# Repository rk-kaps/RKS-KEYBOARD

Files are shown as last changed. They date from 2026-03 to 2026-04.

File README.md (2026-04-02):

# RKS-Keyboard

A mechanical keyboard build on YD-RP2040 with an OLED display and backlights

Build for **MX** switches

A sligthly modified 96% keyboard layout with 4 extra keys for managing onboard firmware (103 keys total)

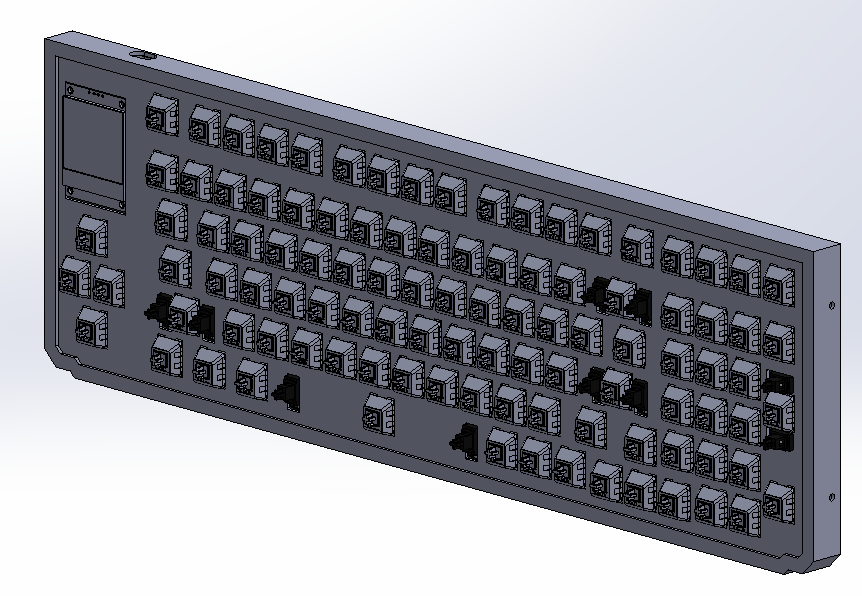
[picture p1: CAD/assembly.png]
Keyboard CAD assembly


Keyboard layout

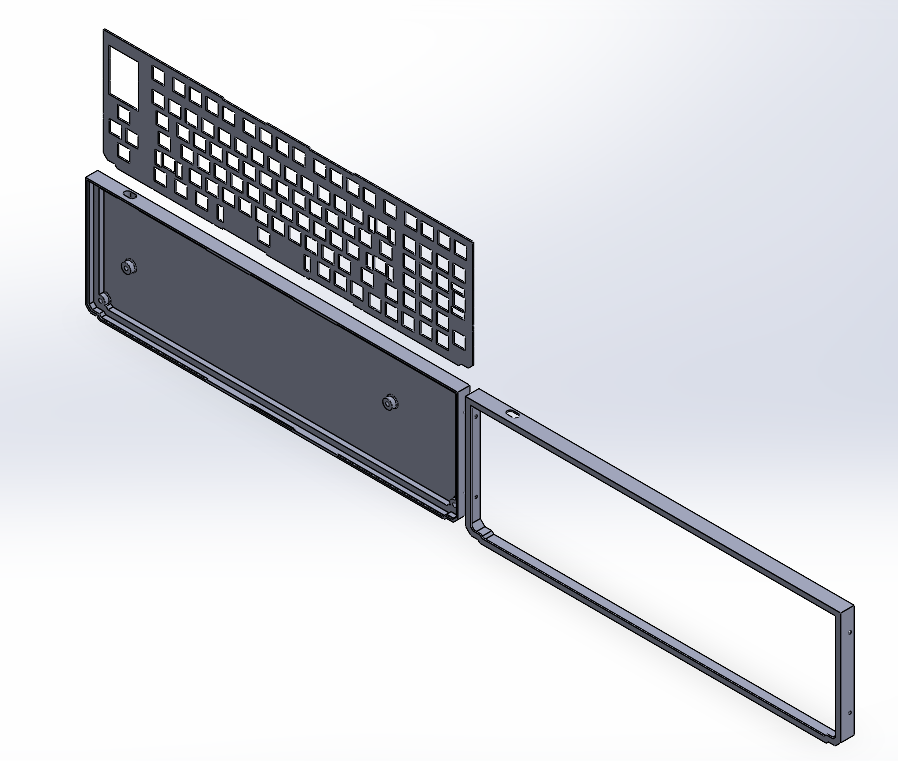
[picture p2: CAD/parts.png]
Keyboard parts


## Why is this one special

It's a keyboard with a customisable OLED that helps to manage, and control parts of the firmware like changing backlighting color, showing typing speed and much more

The firmware is also open-source so anyone can customise and add features to their keyboard

## PCB

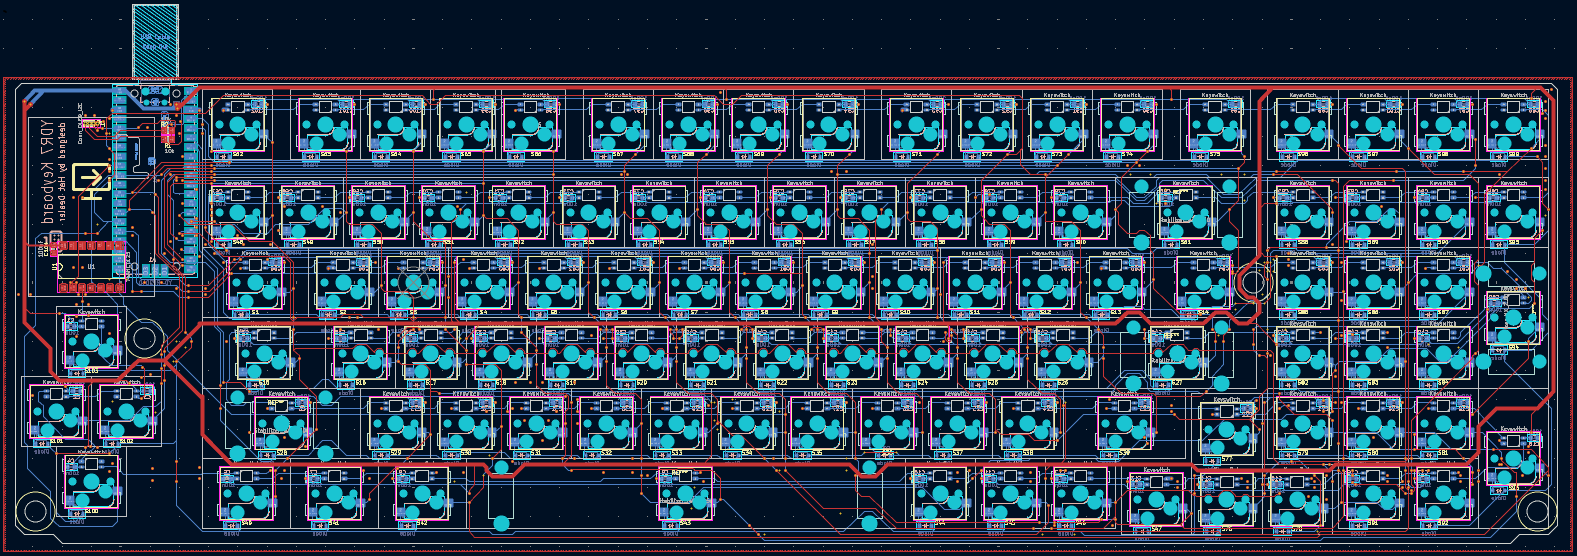
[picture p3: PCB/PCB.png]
PCB


The keyboard uses a custom PCB with the YD-RP2040 attached to it providing a USB-C connection along with power to the board

The YD-RP2040 is the devboard with a chip running this project. You may be able to use a standard Raspberry PI pico but that was not tested

## Case

The keyboard is comprised out of 3 parts. The panel which holds the switches, a back panel and a front panel

Due to their size its impossible to print an entire piece at once, thats why there are sliced versions in the `CAD/Sliced` folder. You can print them separately and then weld them with a soldering iron together. You should weld the front and the back piece but not the panels as they are held together by the frame anyway

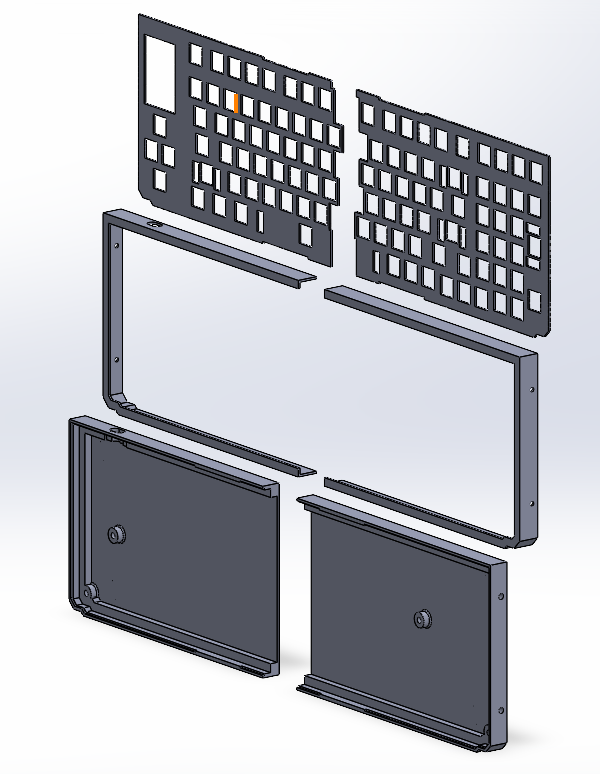
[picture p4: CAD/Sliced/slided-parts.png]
Sliced case


> [!WARNING]
> Due to the size of the keyboard, even the sliced version requires 216 x 139 mm or larger printing plate

## Compiling & flashing firmware

> [!NOTE]
> You should have CMAKE and GCC installed along with Arm embedded GNU Toolchain `arm-none-eabi-gcc`

For compilation run the following commands in the project folder:
Note that the first command may take a while as it is downloading the SDK from git

> cmake -S Firmware -B Firmware/build -G "Ninja"

> cmake --build Firmware/build --target Keyboard_Firmware

To load the firmware into the RP2040 chip, press the **BOOT** button on the YD-RP2040 devboard and plug it into your computer. It should appear as a drive in which you insert the `Keyboard_Firmware.uf2` file inside the `Firmware/build/` folder. The keyboard should reboot itself and load the active firmware

To reflash the board just repeat the steps above

#BOM 

| Ref | Component | Qty | Unit Price (₹) | Total (₹) | Store |
|-----|---|-----|---|---|---|
| MCU | [YD-RP2040](https://probots.co.in/yd-rp2040-4mb-flash-usb-type-c-pico-compatible.html) | 1 | ₹326.54 | ₹326.54 | Probots |
| IC1 | [74AHCT125DR — Logic Level Shifter](https://evelta.com/sn74hct125dr-buffer-line-driver-4ch-non-inverting-3-st-cmos-soic-14/) | 1 | ₹328.72 | ₹328.72 | Evelta |
| C | [100nF 0805 Ceramic Capacitor (≥ 6.3V)](https://robu.in/product/100nf-0805-surface-mount-multilayer-ceramic-capacitor-pack-of-40/) | 105 | ₹2.18 | ₹228.90 | Robu.in |
| R | [10kΩ 0805 Resistor](https://robu.in/product/10k-ohm-1-4w-0805-surface-mount-chip-resistor-pack-of-10/) | 2 | ₹2.18 | ₹4.36 | Robu.in |
| D | [1N4148W Diode (SOD-123)](https://robu.in/product/1n4148w-7-f-diodes-inc-1n4148w-7-f-small-signal-diode-single-100-v-300-ma-1-25-v-4-ns-2-a/) | 103 | ₹2.18 | ₹224.54 | Robu.in |
| HS | [Kailh Hot-Swap Sockets](https://meckeys.com/shop/accessories/keyboard-accessories/key-switches/kailh-hot-swap-socket/) | 103 | ₹899.89 | ₹899.89 | Meckeys |
| SW | [Gateron G Pro 3.0 Switch (MX)](https://meckeys.com/shop/accessories/keyboard-accessories/key-switches/gateron-g-pro-3-0-switch/) | 103 | ₹40.41 | ₹4,162.23 | Meckeys |
| OLED | [1.5" OLED Display 128×128 I2C](https://robu.in/product/0-91-inch-128x32-i2c-iic-serial-blue-oled-lcd-display-module/) | 1 | ₹464.14 | ₹464.14 | Robu.in |
| LED | [SK6812 Mini-E RGB LED ×200](https://stackskb.com/store/) | 2 | ₹369.13 | ₹738.26 | StacksKB |
| KP | [Keycap Set (MX compatible)](https://meckeys.com/category/accessories/keyboard-accessories/keycaps/) | 1 | ₹1,848.93 | ₹1,848.93 | Meckeys |
| SCR | [M3×8 Socket Head Cap Screw](https://robu.in/product/easymech-set-m3-x-8mm-socket-head-cap-allen-bolt-nut-12-pcs/) | 8 | ₹5.46 | ₹43.68 | Robu.in |
| INS | [Hot Melt Insert M3 L4 OD4.2](https://robu.in/product/m3-x-8-mm-brass-heat-set-threaded-round-insert-nut-25-pcs/) | 8 | ₹12.01 | ₹96.08 | Robu.in |
| FEET | [Silicone Feet 12×3mm ×4](https://www.amazon.in/s?k=silicone+feet+12mm+self+adhesive) | 1 | ₹78.63 | ₹78.63 | Amazon.in |
| PCB | [Custom PCB — no assembly](https://jlcpcb.com) | 1 | ₹4,368.40 | ₹4,368.40 | JLCPCB |
| | | | **TOTAL** | **₹13,813.30** | |

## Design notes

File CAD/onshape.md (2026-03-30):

https://cad.onshape.com/documents/5bb766624bd01c39b5b9b201/w/cf6f9baa1b1df1ca9765ea19/e/04b89effa34d09a176b6e1ca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

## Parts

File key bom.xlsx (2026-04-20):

Product Name | Description | Link |  | Qty | Total Cost (₹)
YD-RP2040 | RPI pico-like microcontroller board | Link (https://probots.co.in/yd-rp2040-4mb-flash-usb-type-c-pico-compatible.html) |  | 1 | 235
74AHCT125DR | Logic level shifter IO | Link (https://www.aliexpress.com/item/1005010022053816.html) |  | 10 | 140
100nF 0805 Ceramic Capacitor (>= 6.3V) | Decoupling capacitor | Link (https://robu.in/product/c0805c106m9pactu-kemet-smd-multilayer-ceramic-capacitor-10-µf-6-3-v-0805-2012-metric-±-20-x5r-c-series-kemet/) |  | 105 | 161.7
10kΩ 0805 Resistor | Pull-up resistor | Link (https://quartzcomponents.com/products/10k-ohm-103-5-smd-resistor-0805-pack-of-20-pieces?variant=43451349729514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) |  | 2 | 20
1N4148W Diode | Keyboard matrix diode | Link (https://robu.in/product/1n4148w-slkor-75v-1v-4ns-150ma-sod-123-switching-diodes-rohs/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) |  | 103 | 147.29
Kailh Hot-Swap Sockets for Gateron x103 | PCB sockets for switches | Link (https://stackskb.com/store/gateron-hotswap-sockets/) |  | 103 | 1160
Gateron Switch G Pro 3.0 | Mechanical keyboard switches | Link (https://keychron.in/product/gateron-g-pro-3-0-switch/) |  | 103 | 2799
1.5 Inch OLED Display 128x128 I2C | OLED Screen | Link (https://robu.in/product/1-5-inch-yellow-oled-display-module/) |  | 1 | 464.14
Keycap set | set of keycaps for keyboard | Link (https://stackskb.com/store/hemisphere-keycaps/) |  | 1 | 1999
M3x8 screws | screws for PCB and case assembly | Link (https://onlyscrews.in/products/m3-x-8mm-hex-allen-socket-head-high-tensile12-9-black-anodized-screw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) |  | 8 | 17.6
Hot melt inserts MxL4xOD4.2 | inserts for case assembly | Link (https://onlyscrews.in/products/m4-x-4mm-brass-threaded-inserts?variant=49091565650233) |  | 8 | 18.4
Silicone feet 12x3mm x4 | anti-slip feet for case | Link (https://www.amazon.in/s?k=silicone+rubber+feet) |  | 2 | 260
PCB | w/o assembly (estimate) | Link (https://cart.jlcpcb.com/shopcart/cart/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) |  | 1 | 1994.8
Exchange rate used: 1 EUR = ₹109.21 (as of 29 Mar 2026)
 |  |  | TOTAL COST |  | ₹9416.86 | (excluding shipping
 |  |  |  |  | ₹10999 | with shipping

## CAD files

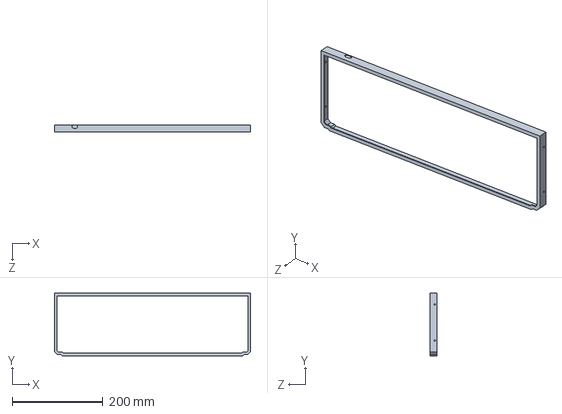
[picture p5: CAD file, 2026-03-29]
CAD/front.SLDPRT
431.7 x 138.0 x 15.6 mm

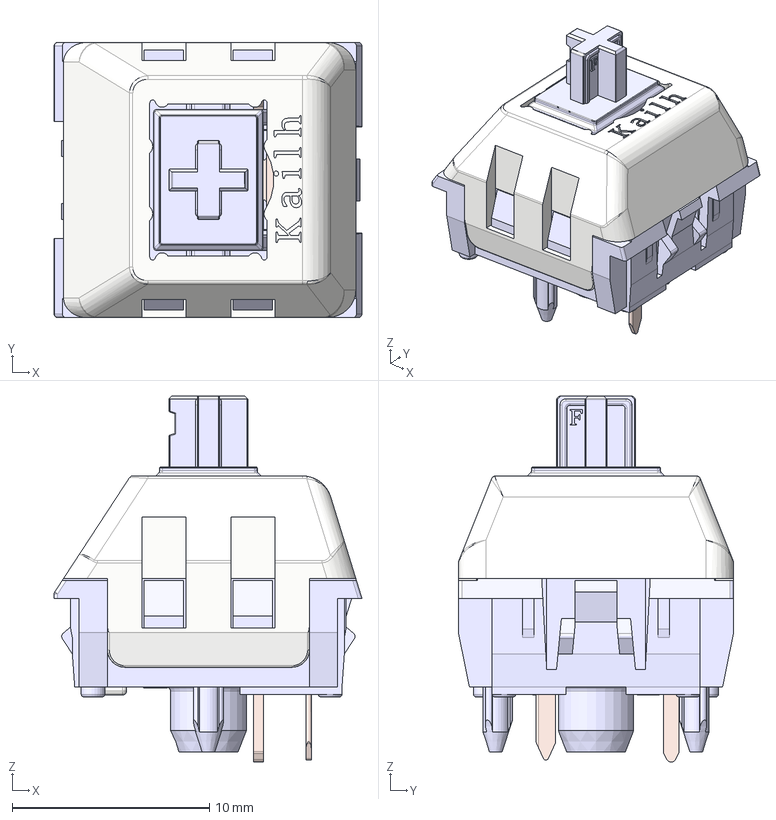
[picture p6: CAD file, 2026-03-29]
PCB/Kailh Polia.step
15.6 x 14.0 x 18.5 mm
Housing
ThickContact
SpringContact
Stem
Lid

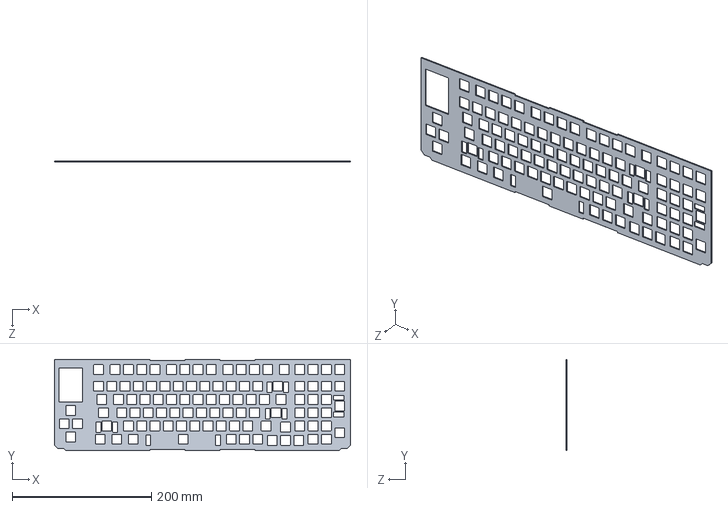
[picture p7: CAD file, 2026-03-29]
CAD/plate.STEP
424.8 x 130.6 x 1.50 mm

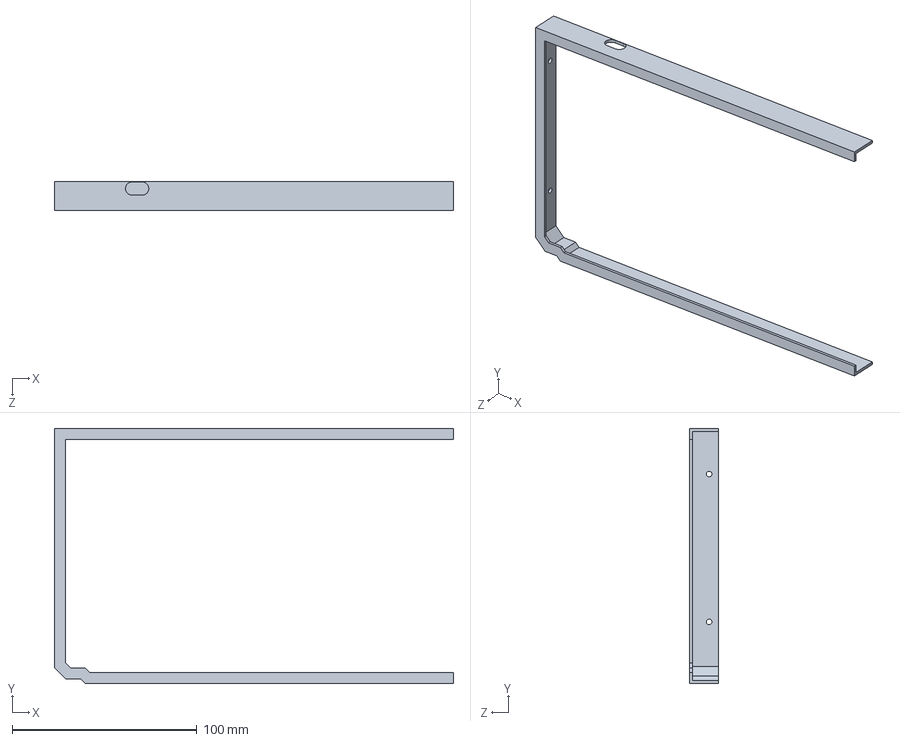
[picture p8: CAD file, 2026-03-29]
CAD/Sliced/1-front.STEP
215.8 x 138.0 x 15.6 mm

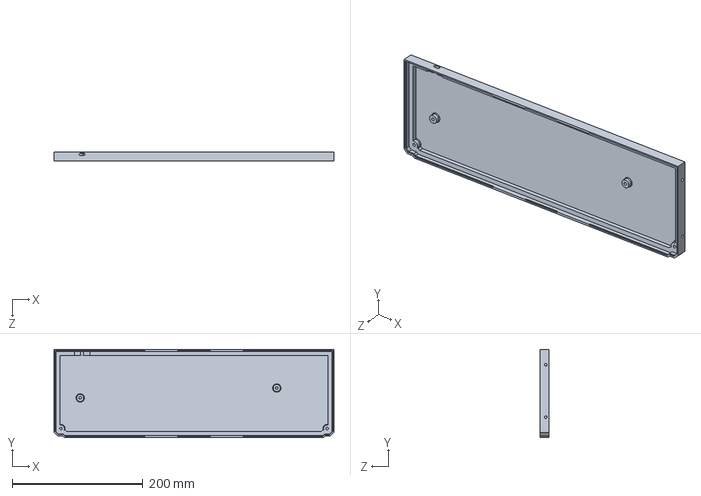
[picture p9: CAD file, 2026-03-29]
CAD/Back.SLDPRT
428.3 x 134.6 x 14.0 mm

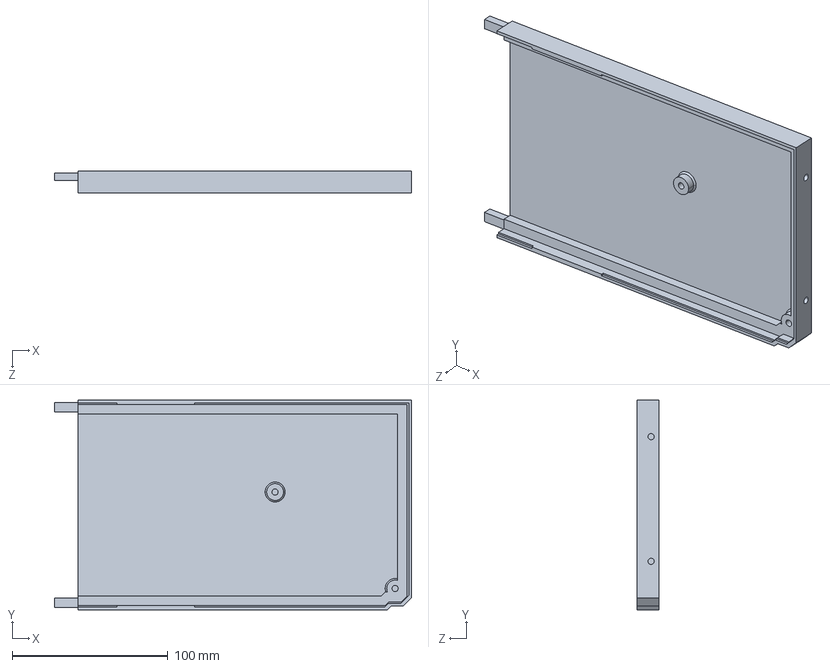
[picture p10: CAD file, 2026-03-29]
CAD/Sliced/2-back.STEP
229.1 x 134.6 x 14.1 mm

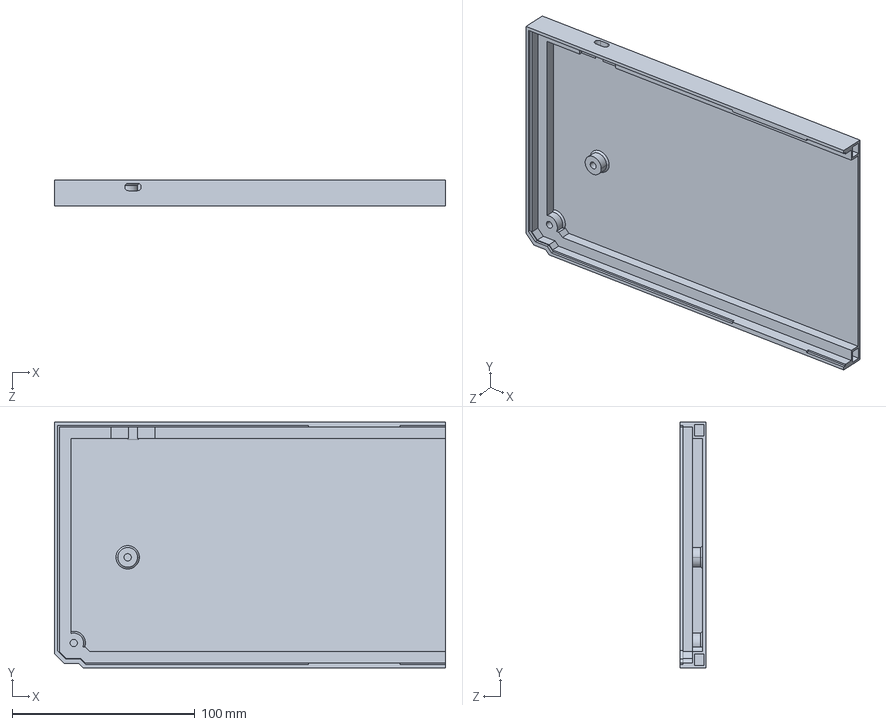
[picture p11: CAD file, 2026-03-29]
CAD/Sliced/1-back.STEP
214.1 x 134.6 x 14.1 mm

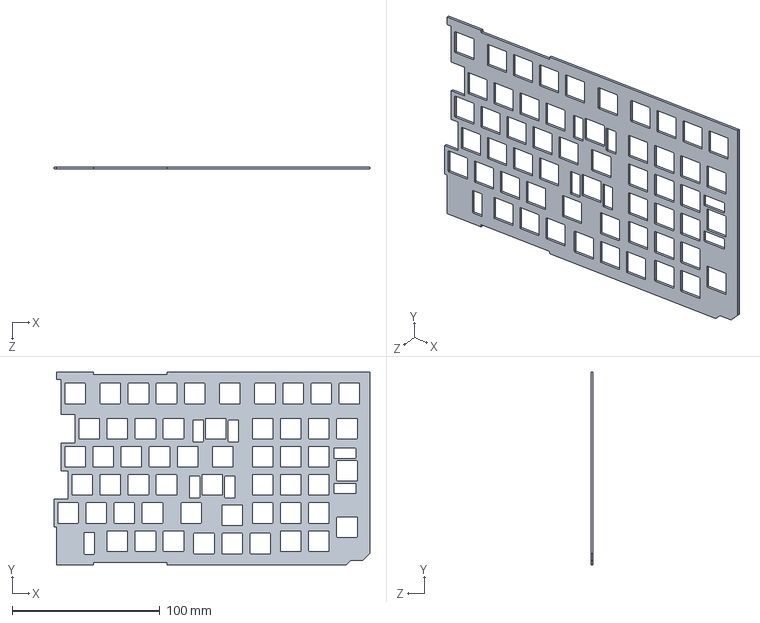
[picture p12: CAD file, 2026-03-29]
CAD/Sliced/2-plate.STEP
214.0 x 130.6 x 1.50 mm

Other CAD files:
CAD/Sliced/Assembly.STEP
CAD/Sliced/1-plate.STEP
CAD/Sliced/2-front.STEP
CAD/Sliced/1-back.SLDPRT
CAD/Sliced/1-back.STL
CAD/Sliced/1-front.SLDPRT
CAD/Sliced/1-front.STL
CAD/Sliced/1-plate.3mf
CAD/Sliced/1-plate.SLDPRT
CAD/Sliced/1-plate.STL
CAD/Sliced/2-back.SLDPRT
CAD/Sliced/2-back.STL
CAD/Sliced/2-front.SLDPRT
CAD/Sliced/2-front.STL
CAD/Sliced/2-plate.SLDPRT
CAD/Sliced/2-plate.STL
CAD/Sliced/Assembly.SLDASM
CAD/back.STL
CAD/plate.SLDPRT
CAD/plate.STL

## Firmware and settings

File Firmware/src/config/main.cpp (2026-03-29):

#include <pico/stdlib.h>
#include <pico/multicore.h>
#include <pico/mutex.h>

#include <atomic>

#include "config/themes.h"
#include "config/user_config.h"

#include "setup/HID_setup.h"
#include "setup/TUD_setup.h"
#include "setup/pin_setup.h"

#include "components/Keyboard.h"
#include "components/LED.h"

mutex_t LEDMutex;
mutex_t DisplayMutex;

std::atomic<bool> updateLEDRequest{false};
std::atomic<bool> updateDisplayRequest{false};

void MULTICORE_DataPushHandler(){
    while(true){
        if(updateLEDRequest.load(std::memory_order_acquire)){
            mutex_enter_blocking(&LEDMutex);
            LED::Show();
            mutex_exit(&LEDMutex);

            updateLEDRequest.store(false,  std::memory_order_release);
        }
        if(updateDisplayRequest.load(std::memory_order_acquire)){
            mutex_enter_blocking(&DisplayMutex);
            Display::Show();
            mutex_exit(&DisplayMutex);
            
            updateDisplayRequest.store(false,  std::memory_order_release);
        }
        sleep_ms(1);
    }
}

int main(){
    PinSetup_ALL();
    Display::InitialScreenWTest();

    tusb_init();

    do{
        tud_task();
        sleep_ms(1);
    }while(!tud_hid_ready());
    
    Display::ClearInitialScreen();

    static float LEDTickTimer = 0;
    constexpr float LEDTickTimerInterval = KEYBOARD_UPDATE_FREQUENCY / static_cast<float>(LED_UPDATE_FREQUENCY);
    static float DisplayTickTimer = 0;
    constexpr float DisplayTickTimerInterval = KEYBOARD_UPDATE_FREQUENCY / static_cast<float>(DISPLAY_UPDATE_FREQUENCY);

    mutex_init(&LEDMutex);
    mutex_init(&DisplayMutex);

    multicore_launch_core1(MULTICORE_DataPushHandler);

    Theme::ApplyTheme(8);

    while (true) {
        tud_task();

        uint8_t* pressedKeys = Keyboard::GetKeyPressIndexes();
        if (pressedKeys) {
            uint8_t report[6] = { 0 };

            for(uint8_t i = 0; i < 6; i++){
                if(pressedKeys[i] != 255){
                    report[i] = Keyboard::KeyMap[pressedKeys[i]];
                    
                    LED::ChangeColor(
                        KEYBOARD_KEY_TO_LED_INDEX[pressedKeys[i]], 
                        Theme::GetActiveColor(), 
                        15
                    );
                } else break;
            }
            tud_hid_keyboard_report(0, 0, report);
        } else {
            tud_hid_keyboard_report(0, 0, nullptr);
            
        }

        if(LEDTickTimer >= LEDTickTimerInterval){
            LEDTickTimer -= LEDTickTimerInterval;

            mutex_enter_blocking(&LEDMutex);
            LED::Tick();
            mutex_exit(&LEDMutex);
            
            updateLEDRequest.store(true, std::memory_order_release);
        }

        if(DisplayTickTimer >= DisplayTickTimerInterval){
            DisplayTickTimer -= DisplayTickTimerInterval;

            mutex_enter_blocking(&DisplayMutex);
            Display::UpdateMenu();
            mutex_exit(&DisplayMutex);

            updateDisplayRequest.store(true, std::memory_order_release);
        }

        static constexpr float KEYBOARD_SLEEP_TIME_MS = 1.0f / KEYBOARD_UPDATE_FREQUENCY * 1000.0f;
        LEDTickTimer += KEYBOARD_SLEEP_TIME_MS;
        DisplayTickTimer += KEYBOARD_SLEEP_TIME_MS;
        sleep_ms(KEYBOARD_SLEEP_TIME_MS);
    }

    return 0;
}

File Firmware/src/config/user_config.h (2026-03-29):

/**
 * USER CONFIG FILE
 * this file is designed to be configured by any end user of the firmware for their keyboard build
 * all the keyboard specific settings are defined in board.h
 * this file only contains settings for specific preferences that are not hardware specific
 * 
 * Most modifications here should be safe or have a warning near them if not
 */

#ifndef CONFIG_H
#define CONFIG_H

#include "config/board.h"
#include "tusb.h"

// Product info
#define MANUFACTURER_NAME "Hat Dealer"
#define PRODUCT_NAME "YDR7 Keyboard"
#define SERIAL_NUMBER "1"

#define KEYBOARD_UPDATE_FREQUENCY 720
#define LED_UPDATE_FREQUENCY 60 // Number of LED ticks per second
#define DISPLAY_UPDATE_FREQUENCY 15

// Time (in ms) without activity before the display goes to sleep
#define DISPLAY_SLEEP_TIMEOUT_MS 10000

#define KEYBOARD_SIGNAL_SETTLE_TIME_US 20

// Keymap
namespace Keyboard{
    const uint8_t KeyMap[K_COLS * K_ROWS] = {
        HID_KEY_ESCAPE,         HID_KEY_F1,             HID_KEY_F2,             HID_KEY_F3,         HID_KEY_F4,                 HID_KEY_F5,         HID_KEY_F6,             HID_KEY_F7,         HID_KEY_F8,         HID_KEY_F9,         HID_KEY_F10,        HID_KEY_F11,            HID_KEY_F12,                HID_KEY_PRINT_SCREEN,
        HID_KEY_GRAVE,          HID_KEY_1,              HID_KEY_2,              HID_KEY_3,          HID_KEY_4,                  HID_KEY_5,          HID_KEY_6,              HID_KEY_7,          HID_KEY_8,          HID_KEY_9,          HID_KEY_0,          HID_KEY_MINUS,          HID_KEY_EQUAL,              HID_KEY_BACKSPACE,
        HID_KEY_TAB,            HID_KEY_Q,              HID_KEY_W,              HID_KEY_E,          HID_KEY_R,                  HID_KEY_T,          HID_KEY_Y,              HID_KEY_U,          HID_KEY_I,          HID_KEY_O,          HID_KEY_P,          HID_KEY_BRACKET_LEFT,   HID_KEY_BRACKET_RIGHT,      HID_KEY_BACKSLASH,
        HID_KEY_CAPS_LOCK,      HID_KEY_A,              HID_KEY_S,              HID_KEY_D,          HID_KEY_F,                  HID_KEY_G,          HID_KEY_H,              HID_KEY_J,          HID_KEY_K,          HID_KEY_L,          HID_KEY_SEMICOLON,  HID_KEY_APOSTROPHE,     HID_KEY_ENTER,              HID_KEY_NONE,
        HID_KEY_SHIFT_LEFT,     HID_KEY_Z,              HID_KEY_X,              HID_KEY_C,          HID_KEY_V,                  HID_KEY_B,          HID_KEY_N,              HID_KEY_M,          HID_KEY_COMMA,      HID_KEY_PERIOD,     HID_KEY_SLASH,      HID_KEY_SHIFT_RIGHT,    HID_KEY_NONE,               HID_KEY_NONE,
        HID_KEY_CONTROL_LEFT,   HID_KEY_GUI_LEFT,       HID_KEY_ALT_LEFT,       HID_KEY_SPACE,      HID_KEY_ALT_RIGHT,          HID_KEY_MENU,       HID_KEY_CONTROL_RIGHT,  HID_KEY_ARROW_LEFT, HID_KEY_ARROW_DOWN, HID_KEY_ARROW_UP,   HID_KEY_SPECIAL_D,  HID_KEY_SPECIAL_L,      HID_KEY_SPECIAL_R,          HID_KEY_SPECIAL_U, // <- special keys
        HID_KEY_ARROW_RIGHT,    HID_KEY_KEYPAD_1,       HID_KEY_KEYPAD_2,       HID_KEY_KEYPAD_3,   HID_KEY_KEYPAD_4,           HID_KEY_KEYPAD_5,   HID_KEY_KEYPAD_6,       HID_KEY_KEYPAD_7,   HID_KEY_KEYPAD_8,   HID_KEY_KEYPAD_9,   HID_KEY_NUM_LOCK,   HID_KEY_KEYPAD_DIVIDE,  HID_KEY_KEYPAD_MULTIPLY,    HID_KEY_NONE,
        HID_KEY_KEYPAD_0,       HID_KEY_KEYPAD_DECIMAL, HID_KEY_KEYPAD_ENTER,   HID_KEY_KEYPAD_ADD, HID_KEY_KEYPAD_SUBTRACT,    HID_KEY_DELETE,     HID_KEY_INSERT,         HID_KEY_PAGE_UP,    HID_KEY_PAGE_DOWN,  HID_KEY_NONE,       HID_KEY_NONE,       HID_KEY_NONE,           HID_KEY_NONE,               HID_KEY_NONE, 
    };
}

// Misc
#define ENABLE_DEBUG_FUNCTIONS
#define OLED_I2C_FREQUENCY 400 * 1000   // 400kHz

// *WARNING*: changing this value can result in permanent damage to the board as the LEDs may draw too much current
// if you are unsure, leave this value as is
// The maximum cumulative R+G+B value for an LED
// precieved brightness should scale logarithmically
#define LED_BRIGHTNESS_VALUE_CAP 20     // 0 - 765

// Special LED key lighting (255 - unset)
#define K_CAPSLOCK_LED_INDEX 33
#define K_NUMLOCK_LED_INDEX 81
#define K_SCROLLLOCK_LED_INDEX 255

// USB Identifiers (placeholder values)
#define USB_VENDOR_ID 0xCafe
#define PRODUCT_ID 0x4000
#define DEVICE_RELEASE_NUMBER 0x0100

#endif

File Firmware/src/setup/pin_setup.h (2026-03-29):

#ifndef PIN_SETUP_H
#define PIN_SETUP_H

#include "hardware/i2c.h"
#include "hardware/adc.h"
#include "config/user_config.h"
#include "config/board.h"
#include "components/Display.h"

namespace Keyboard{
    inline void Setup(){
        // row pins as input
        for(uint8_t r = 0; r < K_ROWS; r++){
            gpio_init(K_ROW_PINS[r]);
            gpio_set_dir(K_ROW_PINS[r], GPIO_IN);
            gpio_pull_down(K_ROW_PINS[r]);
        }

        // column pins as output
        for(uint8_t c = 0; c < K_COLS; c++){
            gpio_init(K_COL_PINS[c]);
            gpio_set_dir(K_COL_PINS[c], GPIO_OUT);
            gpio_put(K_COL_PINS[c], 0);
        }
    }
}

inline float ReadInternalVoltage(){
    adc_select_input(3);
    uint16_t raw = adc_read();

    return raw * 3.3f / (1 << 12) * 3.0f;
}

inline float ReadInternalTemperatureC(){
    adc_select_input(4);
    uint16_t raw = adc_read();

    // some evil math
    float voltage = raw * 3.3f / (1 << 12);
    return 27.0f - (voltage - 0.706f) / 0.001721f;
}

inline void PinSetup_ALL(){
    Display::Setup();
    Keyboard::Setup();

    // Setup ADC for temperature reading
    adc_init();
    adc_set_temp_sensor_enabled(true);

    // Unpower unused pins
    const uint8_t unused_pins[] = UNUSED_PINS;
    for(uint8_t i = 0; i < UNUSED_PINS_COUNT; i++){
        gpio_init(unused_pins[i]);
        gpio_set_dir(unused_pins[i], GPIO_IN);
        gpio_put(unused_pins[i], 0);
    }
};

#endif
